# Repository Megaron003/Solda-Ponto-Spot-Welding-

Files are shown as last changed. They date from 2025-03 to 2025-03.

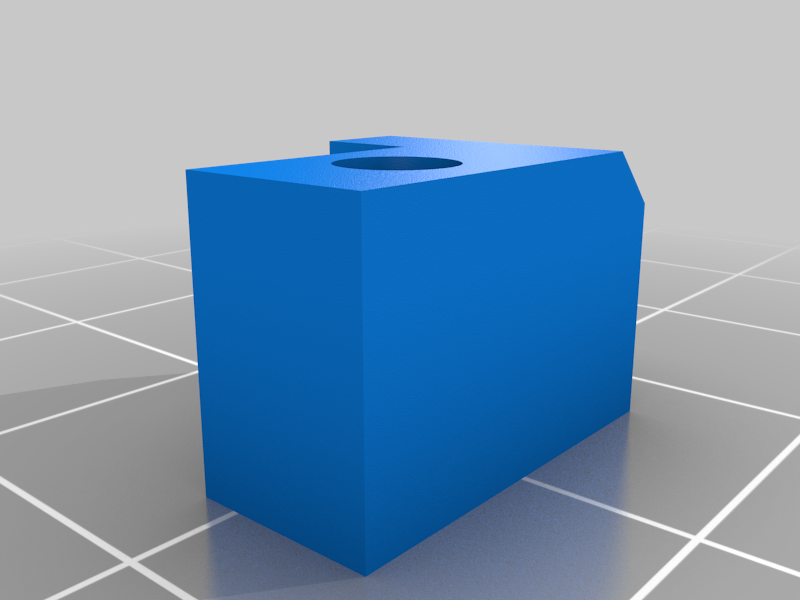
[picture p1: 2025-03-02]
Solda ponto para baterias com Arduino - SpotMaster _ Spot welding for batteries - 6350347/images/4e380fac-cc0a-48aa-a8a8-f89042608fe8.png

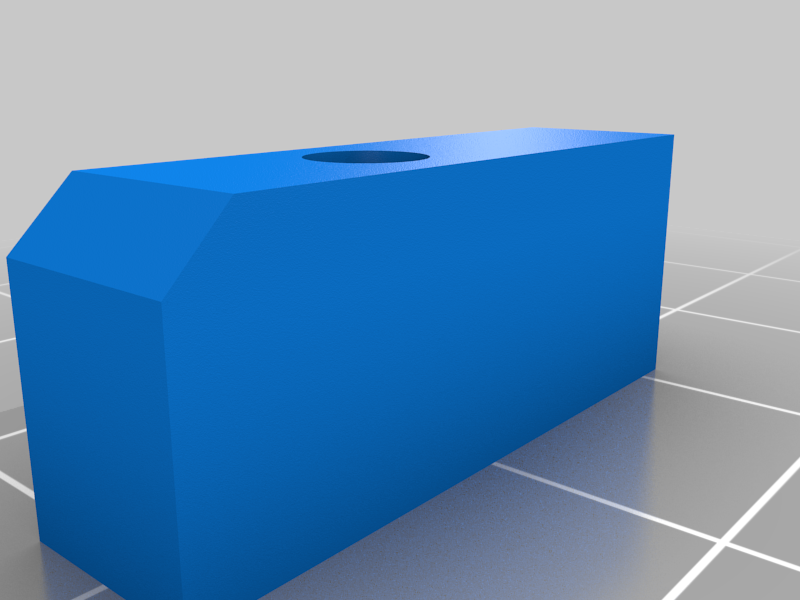
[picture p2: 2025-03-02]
Solda ponto para baterias com Arduino - SpotMaster _ Spot welding for batteries - 6350347/images/a8f08816-faa8-4471-b1d0-5ff337ab06ba.png

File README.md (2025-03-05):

Hello! We are studants of Mato Grosso State University in Brazil and we make this GitHub Repositore to help all people that found us to create a spot welding make by yourselves.
All of information that exist in this GitHub repositore comes from Marlon Nardi's YouTube Channel. Therefore, thank you8 very much, Marlon Nardi!

Marlon Nardi's YouTube Channel link: https://www.youtube.com/@MarlonNardi

Marlon Nardi's Spot Welding video link: https://www.youtube.com/watch?v=JuG6gNFQjxI

Link to the Marlon Nardi's Website project: https://marlonnardi.com/2023/12/03/como-fazer-solda-ponto-profissional-para-baterias-18650-e-mais-construa-sua-propria-bicicleta-eletrica-1/

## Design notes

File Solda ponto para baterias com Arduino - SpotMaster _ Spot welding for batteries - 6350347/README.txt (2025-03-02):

Solda ponto para baterias com Arduino - SpotMaster | Spot welding for batteries by MarlonNW on Thingiverse: https://www.thingiverse.com/thing:6350347

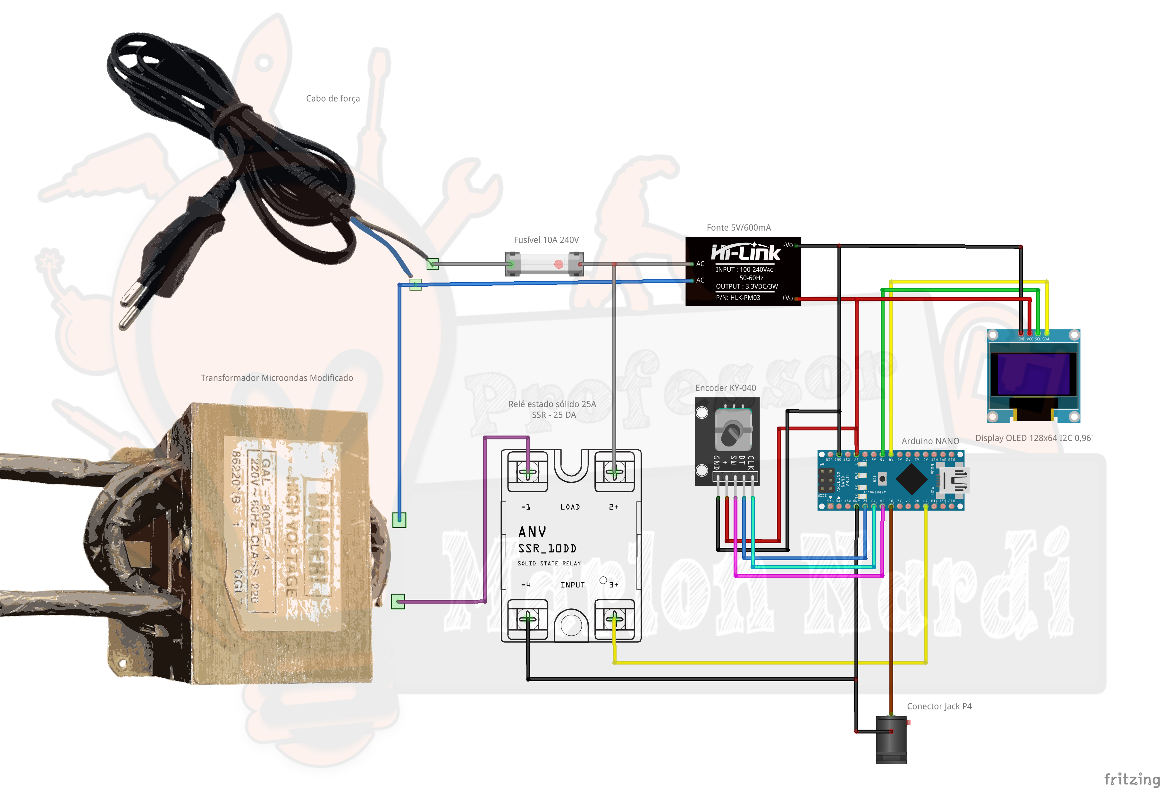
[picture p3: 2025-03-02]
Circuito-Solda-Ponto-com-Arduino-SpotMaster-Marlon-Nardi.png

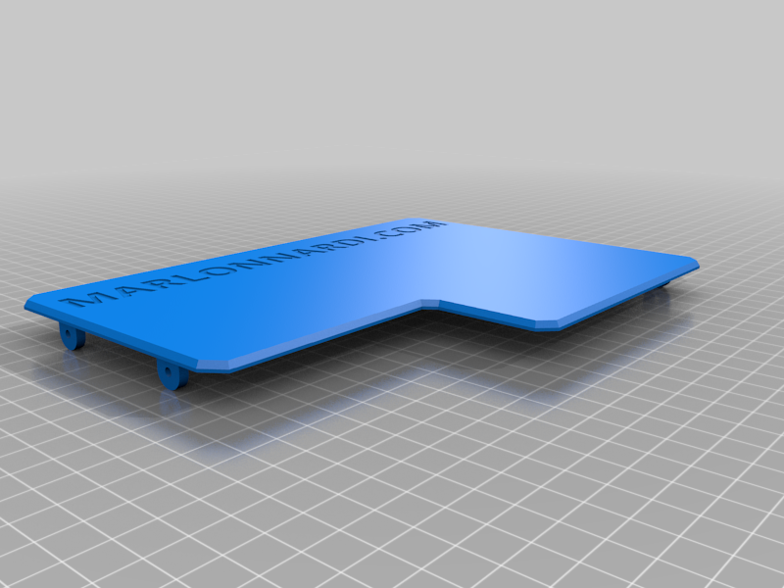
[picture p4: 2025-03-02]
Solda ponto para baterias com Arduino - SpotMaster _ Spot welding for batteries - 6350347/images/35b4dd96-6c8e-40c9-b999-e3f31643d9b3.png

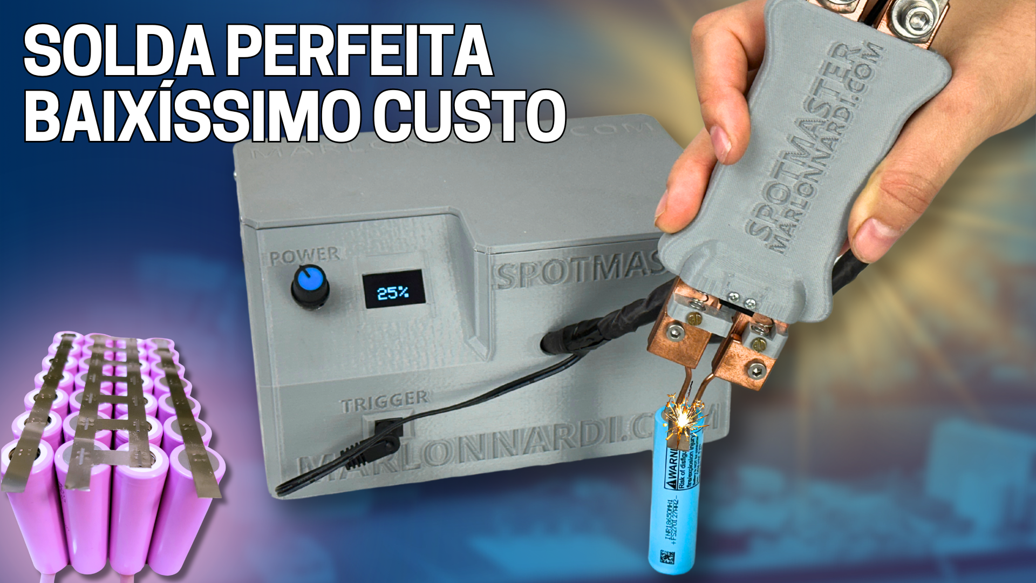
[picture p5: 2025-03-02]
Solda ponto para baterias com Arduino - SpotMaster _ Spot welding for batteries - 6350347/images/a2911549-ac34-4346-8438-8d530a35a111.png

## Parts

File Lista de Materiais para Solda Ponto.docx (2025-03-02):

Lista de Materiais Solda Ponto

- 1 – Arduino NANO; (30 reais)
- 1 – Fonte Hilink 5VDC/600mA; (40 reais)
- 1 – Módulo Encoder Rotativo KY-040; (15 reais)
- 1 – Rele estado sólido de 25A modelo SSR- 25 DA | Clique aqui para comprar no mesmo lugar que eu (https://mercadolivre.com/sec/2ki5AWu); (40 reais)
- 1 – Knob para encoder; (5 reais)
- 1 – Cabo de força para tomada; (30 reais)
- 1 – Display OLED I2C 0.96Inch 128×64; (8 - 35 reais)
- 1 – Conector tipo Jack fêmea de 5.5mm; (5 reais)
- 1 – Cabo duplo retirado de fonte de modem com conector Jack macho de 5.5mm; (16 reais)
- 1 – Transformador de microondas; (100 reais)
- 2 – Metros de cabo flexível de cobre de 35mm²; (152 reais – 20 metros)
- 2 – Terminais de compressão tipo olhal para cabo de 35mm²; (50 reais – 10 unidades)
- 2 – Duas barras de cobre de cobre chatas 3/4 x 3/16 (19mm x 4,76mm) com 25 cm cada | Clique aqui para comprar no mesmo lugar que eu (https://mercadolivre.com/sec/2HVnAhZ); (40 reais cada)
- 1 – Mola de mesa de impressora 3D fina; (20 reais)
- Diversos parafusos para montagem (ver vídeo);
- Peças impressão em 3D;
- 5 – Metros fios elétricos flexíveis de 0,5mm²; (60 reais – 100 metros)

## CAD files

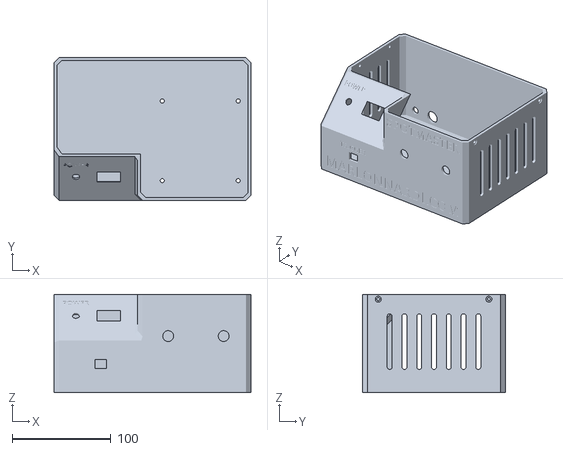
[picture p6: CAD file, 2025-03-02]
Solda ponto para baterias com Arduino - SpotMaster _ Spot welding for batteries - 6350347/files/2_-_Case_-_SpotMaster.stl
200.0 x 145.0 x 100.0

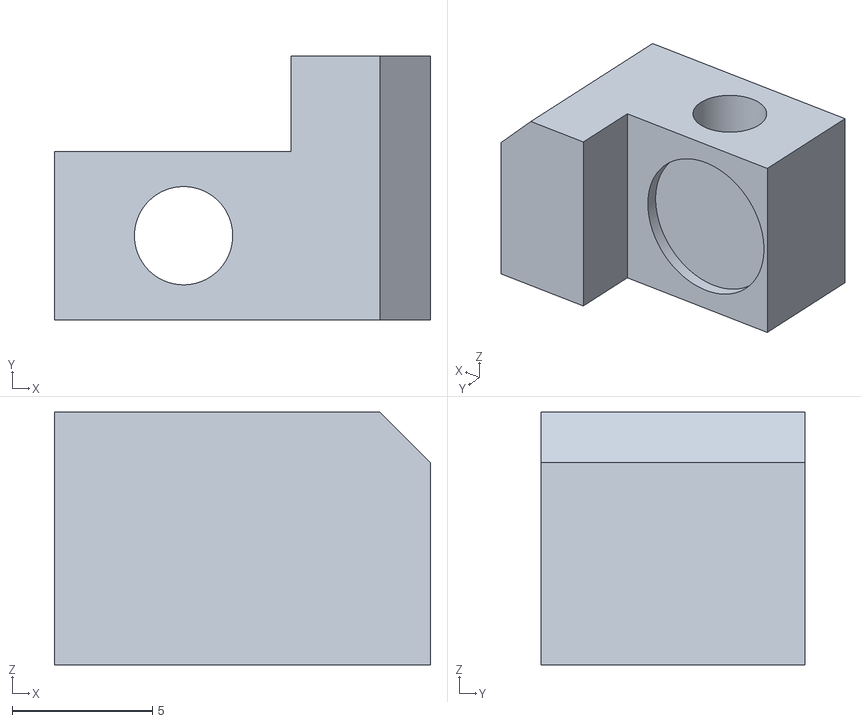
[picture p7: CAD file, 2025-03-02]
Solda ponto para baterias com Arduino - SpotMaster _ Spot welding for batteries - 6350347/files/5_-_Suporte_mola_2_-_SpotMaster.stl
13.4 x 9.40 x 9.00

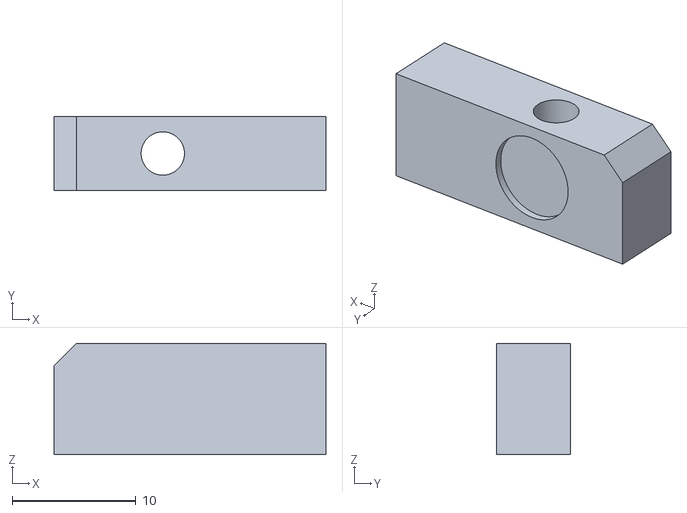
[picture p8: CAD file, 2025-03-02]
Solda ponto para baterias com Arduino - SpotMaster _ Spot welding for batteries - 6350347/files/4_-_Suporte_mola_1_-_SpotMaster.stl
22.0 x 6.00 x 9.00

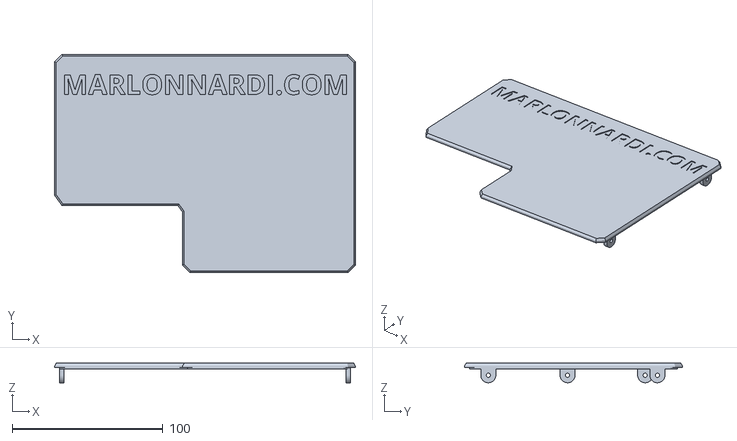
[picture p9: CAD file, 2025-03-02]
Solda ponto para baterias com Arduino - SpotMaster _ Spot welding for batteries - 6350347/files/3_-_Tampa_Case_-_SpotMaster.stl
200.0 x 145.0 x 13.0

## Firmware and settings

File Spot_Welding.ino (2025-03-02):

/*********************************************
  Autor: Marlon Nardi Walendorff
  Projeto: Solda ponto para baterias de lítio com Arduino
  Detalhes do projeto:https://marlonnardi.com/2023/12/03/como-fazer-solda-ponto-profissional-para-baterias-18650-e-mais-construa-sua-propria-bicicleta-eletrica-1/
  /**********************************************/
 
 
//==================== Inclusão de Bibliotecas =================//
#include <Adafruit_SSD1306.h>
#include <RotaryEncoder.h>
 
//==================== Mapeamento de Hardware ==================//
#define pin_Encoder_CLK 3
#define pin_Encoder_DT 2
#define pin_Encoder_SW 4
 
#define pin_Trigger 5
#define pin_Triac 9
 
#define min_Power_ms 3
#define max_Power_ms 120
 
//==================== Instânciando Objetos ====================//
Adafruit_SSD1306 Display(128, 64, &Wire, -1, 400000, 400000);
RotaryEncoder EncoderOne(pin_Encoder_CLK, pin_Encoder_DT);
 
//==================== Variáveis Globais ==================//
byte aux2 = 0;
 
int16_t valorEncoder = 0;
uint16_t time_ms = 0;
 
 
void setup()
{
 
  Serial.begin(9600);
  //Configura pino como saída
  pinMode(pin_Triac, OUTPUT);
 
  //Configura pino como entrada PULL-UP
  pinMode(pin_Encoder_SW, INPUT_PULLUP);
  //Configura pino como entrada PULL-UP
  pinMode(pin_Trigger, INPUT_PULLUP);
 
 
 
  //================= Interrupção Externa ========================//
  /* Vincula duas interrupções externas no pino 2 e 3 nas funções ISR0 e ISR1
     para garantir que o encoder sempre seja lido com prioridade.*/
  attachInterrupt(digitalPinToInterrupt(2), ISR0, CHANGE);
  attachInterrupt(digitalPinToInterrupt(3), ISR1, CHANGE);
 
  EncoderOne.setPosition(25); // Energia inicial em 25%
 
  //Inicializa o OLED 128X64 0.96 INCH com endereço I2C 0x3C
  Display.begin(SSD1306_SWITCHCAPVCC, 0x3C);
 
  Display.setTextColor(WHITE); //Define a cor do texto
 
 
  //Limpa o display, necessário para apagar a imagem inicial da adafruit
  Display.clearDisplay();
  //Atualiza o display
  Display.display();
 
 
 
  Display.setTextSize(1); //Define o tamanho da fonte do texto
  //Posição Largura/Altura
  Display.setCursor(0, 0);
  Display.print("Acesse o projeto em:");
 
  Display.setTextSize(1); //Define o tamanho da fonte do texto
  //Posição Largura/Altura
  Display.setCursor(0, 25);
  Display.print("marlonnardi.com");
 
  Display.display();
 
 
  delay(2000);
 
  Display.clearDisplay();
  Display.display();
 
 
}//endSetup --------------------------------------
 
 
void loop()
{
  trigger();
  screenOne();
}//end_void_loop ----------------------
 
 
 
void trigger()
{
 
  if (digitalRead(pin_Trigger) ) //Se o botão está solto
  {
    aux2 = 1;
  }
 
  if (!digitalRead(pin_Trigger) && aux2 == 1) //Se o botão está pressionado
  {
 
    digitalWrite(pin_Triac, HIGH);
    delay(time_ms);
    digitalWrite(pin_Triac, LOW);
    delay(time_ms);
 
    aux2 = 0;
  }
 
 
}//----------------------- end_selecionaTela
 
 
//================== ISRs Interrupções Externas =======================//
/* Caso qualquer pino do encoder envie sinal, o metodo .tick() sempre será
  chamado, atualizando o valor do encoder via sua biblioteca. */
 
void ISR0()// Função ligada a uma interrupção ISR logo não pode retornar valor e deve ser mais rápida possível
{
  EncoderOne.tick();// Começa a ler o valor do encoder
}//-------------------------endISR0
 
void ISR1()// Função ligada a uma interrupção ISR logo não pode retornar valor e deve ser mais rápida possível
{
  EncoderOne.tick();// Começa a ler o valor do encoder
 
}//------------------------endISR1
 
 
void screenOne()
{
  Display.clearDisplay();
 
  Display.setTextSize(2); //Define o tamanho da fonte do texto
  //Posição Largura/Altura
  Display.setCursor(27, 0);
  Display.print("Energy:");
 
 
  if (valorEncoder <= 9)
  {
    Display.setTextSize(4); //Define o tamanho da fonte do texto
    //Posição Largura/Altura
    Display.setCursor(46, 25);
    Display.print(valorEncoder);
 
    //Posição Largura/Altura
    Display.setCursor(71, 25);
    Display.print("%");
 
  }
 
  if (valorEncoder >= 10 && valorEncoder <= 99)
  {
 
    Display.setTextSize(4); //Define o tamanho da fonte do texto
    //Posição Largura/Altura
    Display.setCursor(31, 25);
    Display.print(valorEncoder);
 
    //Posição Largura/Altura
    Display.setCursor(81, 25);
    Display.print("%");
 
  }
 
  if (valorEncoder >= 100)
  {
 
    Display.setTextSize(4); //Define o tamanho da fonte do texto
    //Posição Largura/Altura
    Display.setCursor(18, 25);
    Display.print(valorEncoder);
 
    //Posição Largura/Altura
    Display.setCursor(92, 25);
    Display.print("%");
 
  }
 
 
 
 
  valorEncoder = EncoderOne.getPosition();//Captura o valor do encoder
 
  if (EncoderOne.getPosition() < 1)
  {
    EncoderOne.setPosition(1);
    valorEncoder = 1;
  }
 
  if (EncoderOne.getPosition() > 100)
  {
    EncoderOne.setPosition(100);
    valorEncoder = 100;
  }
 
 
  time_ms = map(valorEncoder, 1, 100, min_Power_ms, max_Power_ms);
 
  Serial.println(time_ms);
 
 
  Display.display();
 
}//end_screenOne ----------------------

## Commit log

2025-03-02 Spot Welding code for an Arduino nano
2025-03-02 Eletric Circuit of Spot Welding
2025-03-02 3D files to impress
    All files to make the 3D impression from Thingiserve
    [2_-_Case_-_SpotMaster.stl, 3_-_Tampa_Case_-_SpotMaster.stl, 4_-_Suporte_mola_1_-_SpotMaster.stl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]
